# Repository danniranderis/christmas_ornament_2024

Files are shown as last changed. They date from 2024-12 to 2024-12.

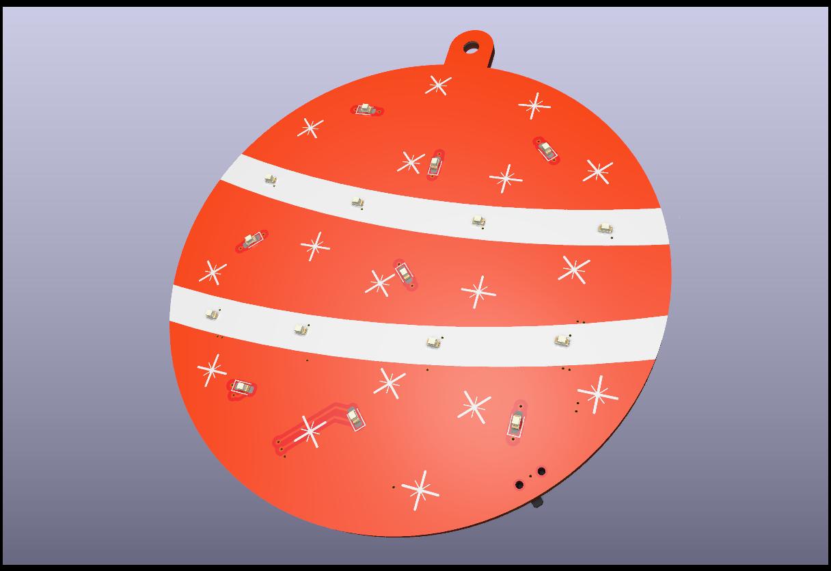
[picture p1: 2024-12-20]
Documentation/christmas_ornament_2024_front_tilt.jpg

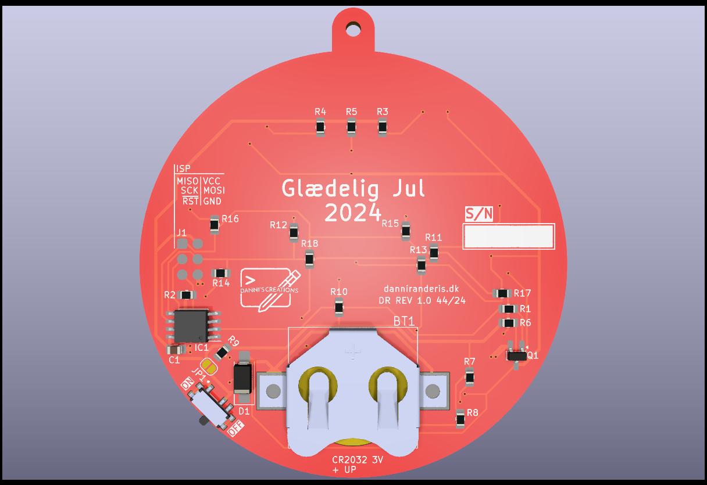
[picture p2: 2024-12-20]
Documentation/christmas_ornament_2024_back.jpg

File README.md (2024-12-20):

# Christmas Ornament 2024
This year marks the second time creating an electronics project for the Christmas holidays.  
The pcb resembles a Christmas ornament-ball in red with silkscreen and LEDs for a twinkling star effect.

## Hardware
The "Hardware" directory within this repository contains PCB design as a KiCAD 8.0 project.

## Firmware
The "Firmware" directory within this repository contains the firmware for the ATtiny13 MCU as an Arduino project.
This utilizes the [Microcore](https://github.com/MCUdude/MicroCore) hardware package.

## Documentation
The "Documentation" directory within this repository contains various documentation-files for the project. Find PDFs, images and alike herewithin.

## Credits
- Danni Randeris <danni@danniranderis.dk>

## License
Copyright 2024 Danni Randeris

This project is licensed under the TAPR Open Hardware License (www.tapr.org/OHL). The "license" folder within this repository contains a copy of this license in plain text format.

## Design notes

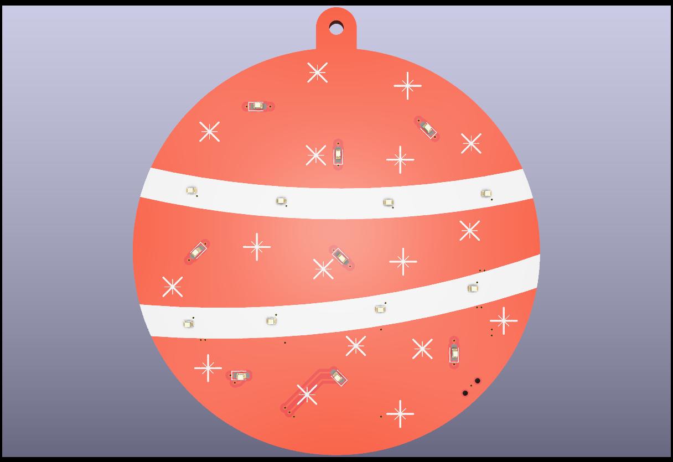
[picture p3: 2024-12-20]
Documentation/christmas_ornament_2024_front.jpg

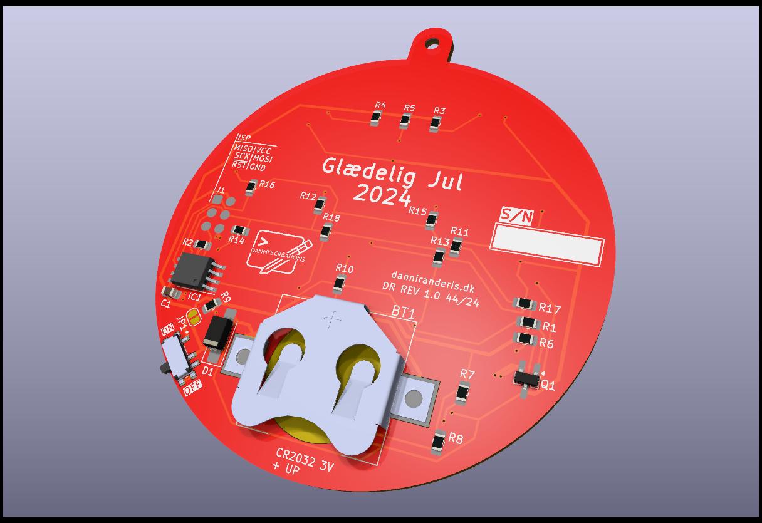
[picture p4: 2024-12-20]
Documentation/christmas_ornament_2024_back_tilt.jpg

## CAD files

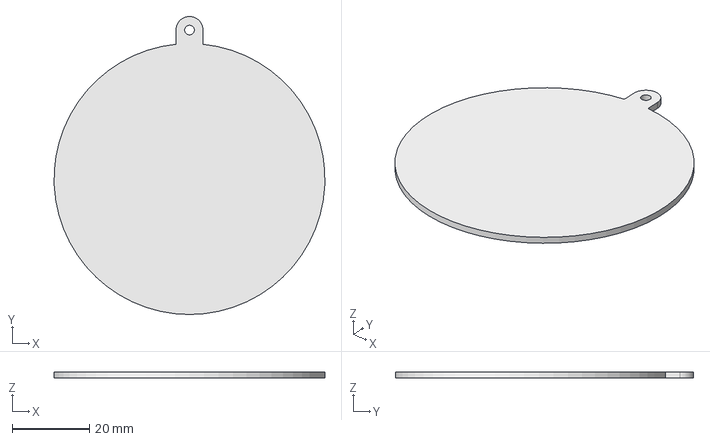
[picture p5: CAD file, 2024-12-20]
Hardware/pcb_edge_cut.FCStd
69.9 x 77.0 x 1.60 mm

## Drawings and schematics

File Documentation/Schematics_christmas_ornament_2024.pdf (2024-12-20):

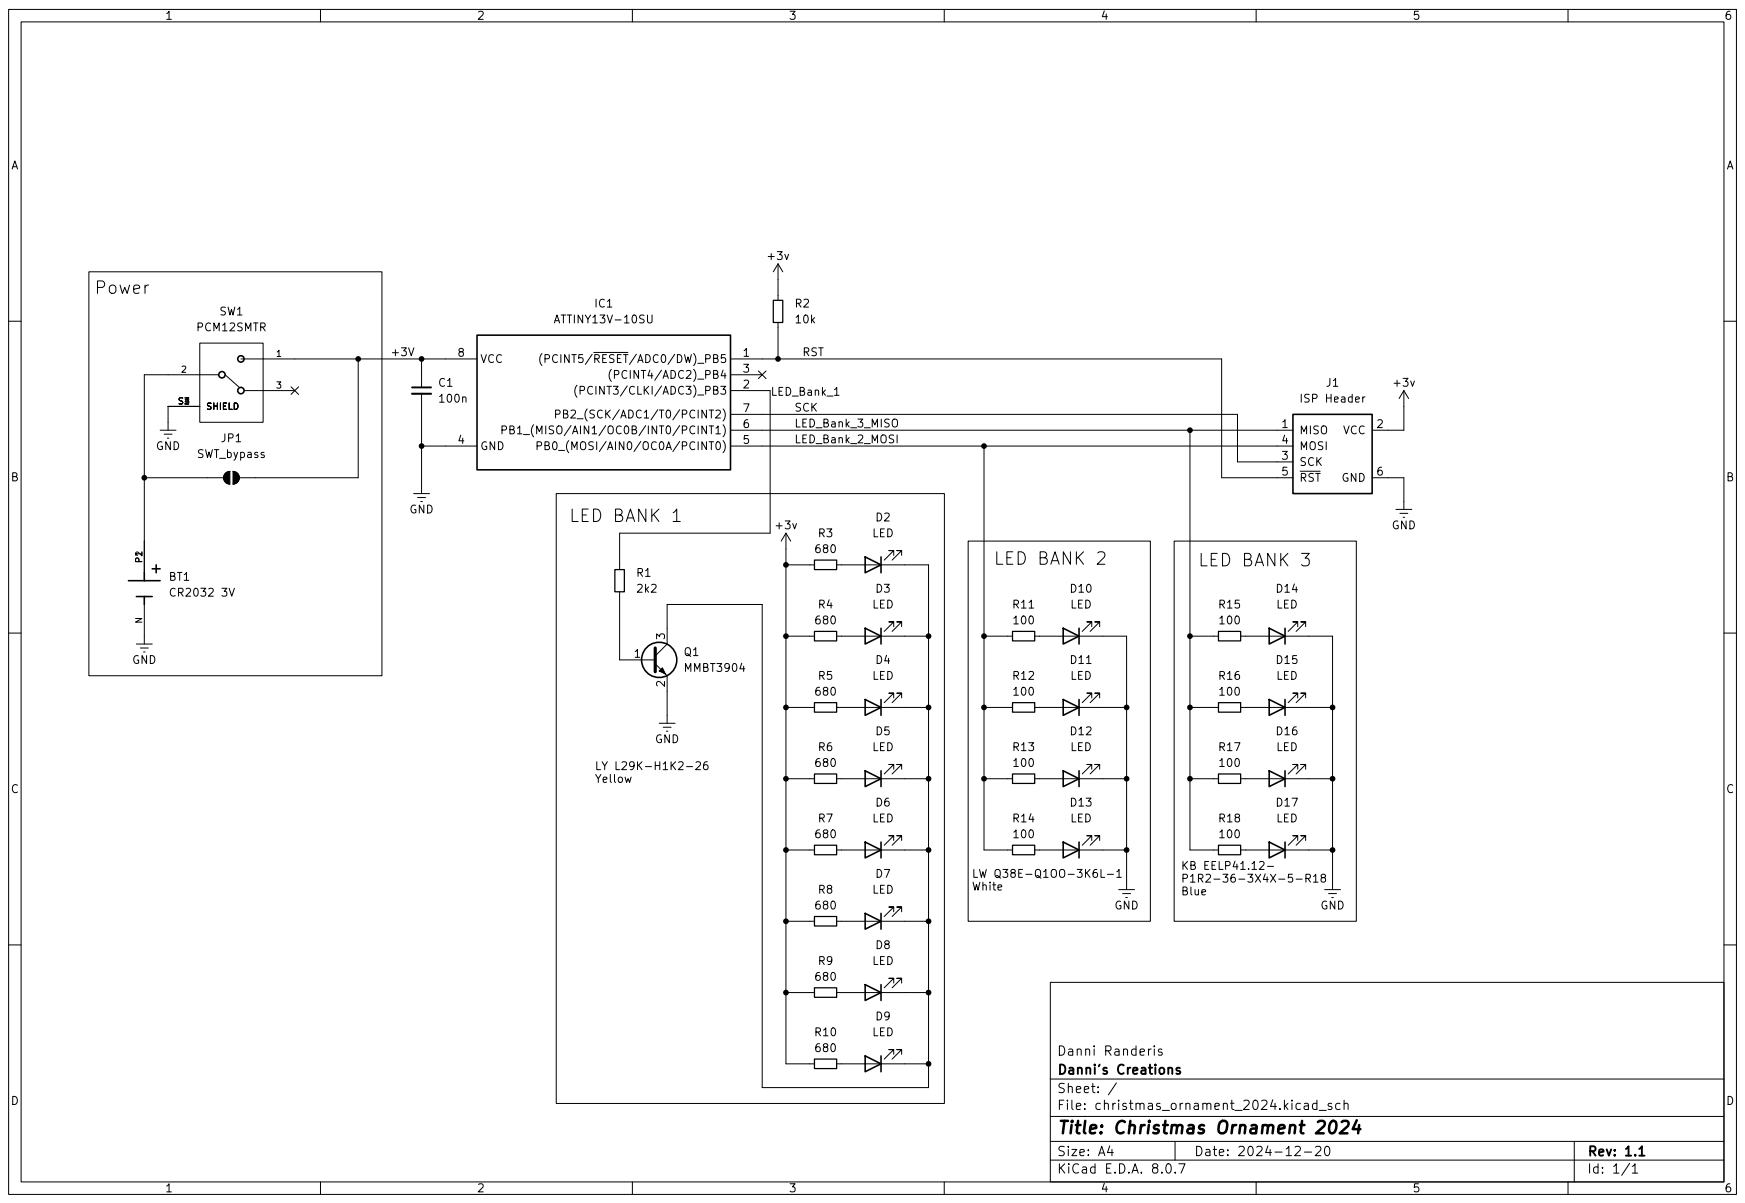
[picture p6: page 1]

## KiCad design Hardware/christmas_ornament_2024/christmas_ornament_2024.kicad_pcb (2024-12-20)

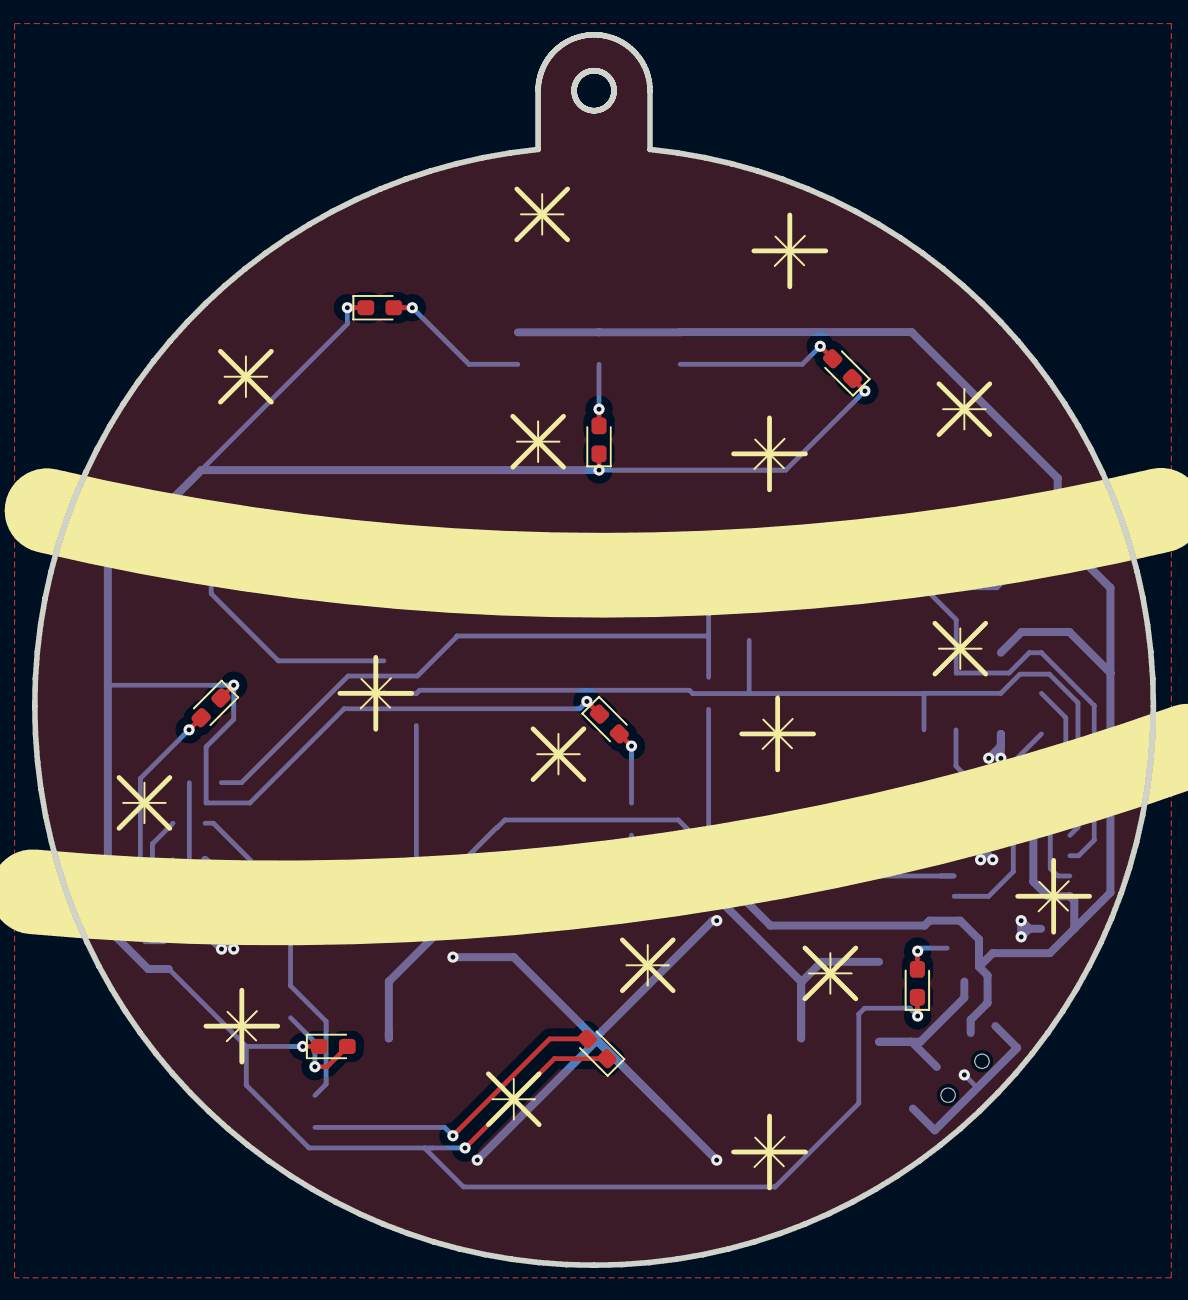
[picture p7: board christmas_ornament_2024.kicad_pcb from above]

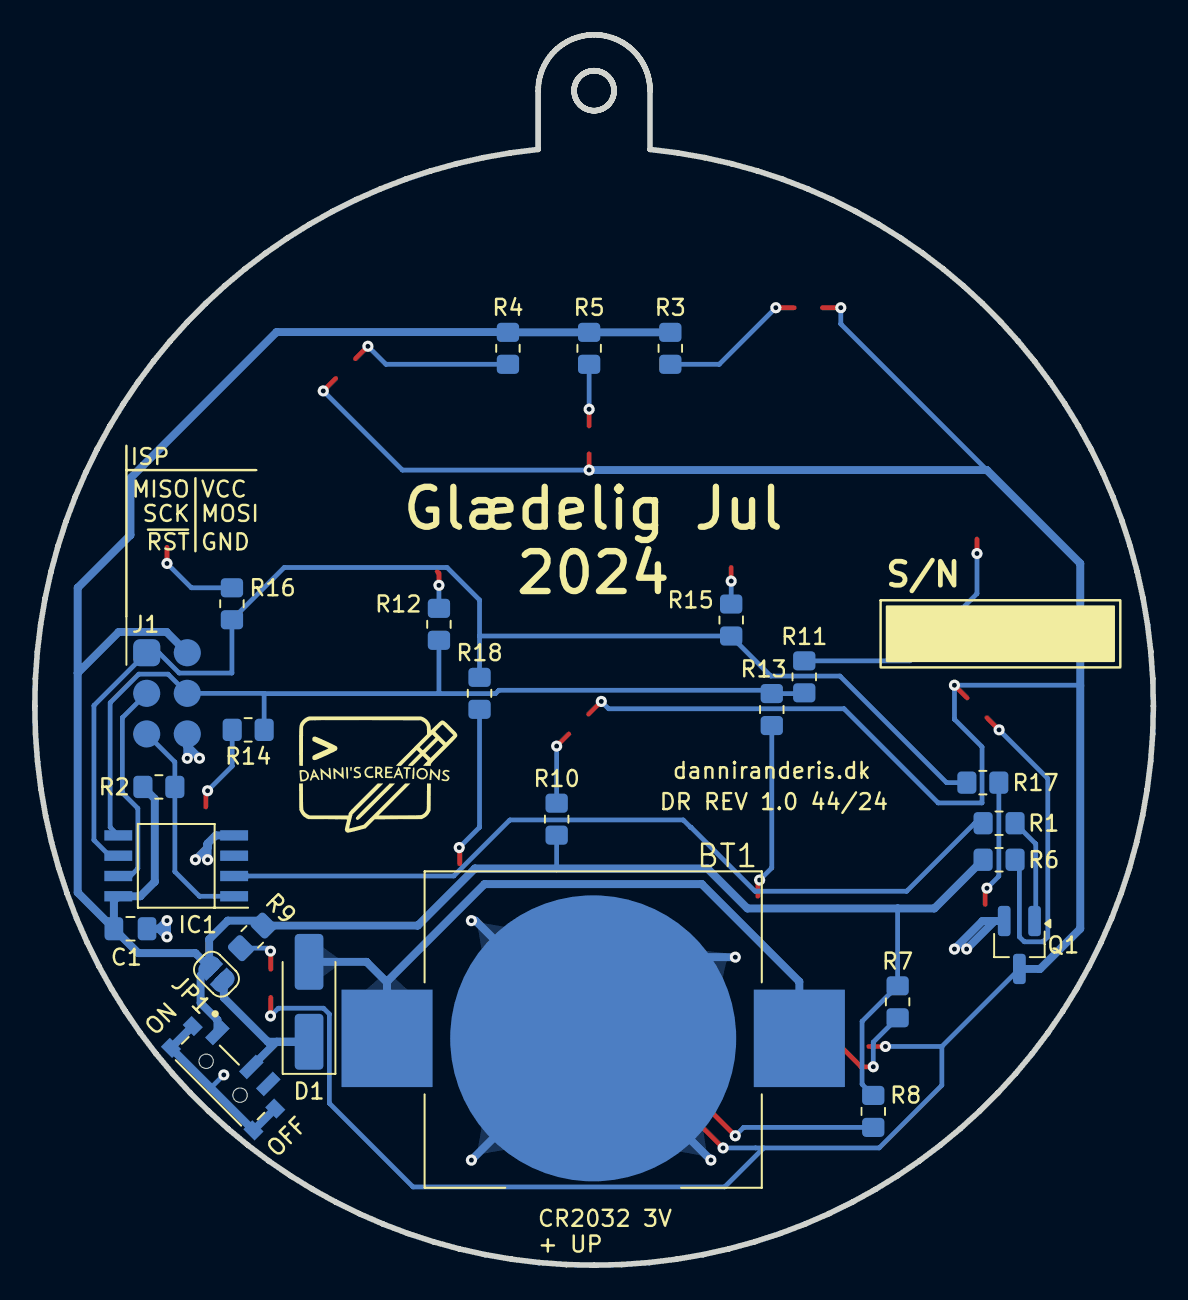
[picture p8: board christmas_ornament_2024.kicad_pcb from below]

Board: 2 copper layers, 70.0 x 77.0 mm, 59 parts (26 on the bottom side), 27 nets.

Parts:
BT1: CR2032 3V; BAT_BAT-HLD-003-SMT
C1: 100n; C_0805_2012Metric_Pad1.18x1.45mm_HandSolder
D1: SS12; D_SMA_Handsoldering
D2, D3, D4, D5, D6, D7, D8, D9, D10, D11, D12, D13, D14, D15, D16, D17: LED; LED_0603_1608Metric_Pad1.05x0.95mm_HandSolder
IC1: ATTINY13V-10SU; SOIC127P798X216-8N
J1: ISP Header; ISP_Pad
JP1: SWT_bypass; SolderJumper-2_P1.3mm_Open_RoundedPad1.0x1.5mm
Q1: MMBT3904; SOT-23_Handsoldering
R1: 2k2; R_0805_2012Metric_Pad1.20x1.40mm_HandSolder
R2: 10k; R_0805_2012Metric_Pad1.20x1.40mm_HandSolder
R3, R4, R5, R6, R7, R8, R9, R10, R11, R12, R13, R14, R15, R16, R17, R18: 470; R_0805_2012Metric_Pad1.20x1.40mm_HandSolder
SW1: PCM12SMTR; SW_PCM12SMTR
U1, U2, U3, U4, U5, U6, U7, U10, U11, U12, U13, U14, U15, U16, U17, U18, U19: star

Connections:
+3V: C1.1, IC1.8 (VCC), J1.2 (VCC), JP1.2 (B), R2.1, R3.1, R4.1, R5.1, R6.1, R7.1, R8.1, R9.1, R10.1, SW1.1
/LED_Bank_1: IC1.2 ((PCINT3/CLKI/ADC3)_PB3), R1.2
/LED_Bank_2_MOSI: IC1.5 (PB0_(MOSI/AIN0/OC0A/PCINT0)), J1.4 (MOSI), R11.1, R12.1, R13.1, R14.1
/LED_Bank_3_MISO: IC1.6 (PB1_(MISO/AIN1/OC0B/INT0/PCINT1)), J1.1 (MISO), R15.1, R16.1, R17.1, R18.1
/RST: IC1.1 ((PCINT5/~RESET/ADC0/DW)_PB5), J1.5 (~RST), R2.2
/SCK: IC1.7 (PB2_(SCK/ADC1/T0/PCINT2)), J1.3 (SCK)
DARAN_GND: BT1.N, C1.2, D10.1 (K), D11.1 (K), D12.1 (K), D13.1 (K), D14.1 (K), D15.1 (K), D16.1 (K), D17.1 (K), IC1.4 (GND), J1.6 (GND), Q1.2 (E), SW1.S1 (SHIELD), SW1.S2 (SHIELD), SW1.S3 (SHIELD), SW1.S4 (SHIELD)
unnamed: BT1.P1, BT1.P2, D1.2 (A)
unnamed: D1.1 (K), JP1.1 (A), SW1.2
unnamed: D2.2 (A), R3.2
unnamed: D2.1 (K), D3.1 (K), D4.1 (K), D5.1 (K), D6.1 (K), D7.1 (K), D8.1 (K), D9.1 (K), Q1.3 (C)
unnamed: D3.2 (A), R4.2
unnamed: D4.2 (A), R5.2
unnamed: D5.2 (A), R6.2
unnamed: D6.2 (A), R7.2
unnamed: D7.2 (A), R8.2
unnamed: D8.2 (A), R9.2
unnamed: D9.2 (A), R10.2
unnamed: D10.2 (A), R11.2
unnamed: D11.2 (A), R12.2
unnamed: D12.2 (A), R13.2
unnamed: D13.2 (A), R14.2
unnamed: D14.2 (A), R15.2
unnamed: D15.2 (A), R16.2
unnamed: D16.2 (A), R17.2
unnamed: D17.2 (A), R18.2
unnamed: Q1.1 (B), R1.1

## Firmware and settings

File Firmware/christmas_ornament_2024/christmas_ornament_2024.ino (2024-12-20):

/**
  Christmas Ornamant 2024 firmware for ATtiny13.

  Three banks of LEDs, Yellow, White, and Blue.
  The Yellow bank is always on, while the white and blue are
  twinkling with seperate randomness.

  Written by Danni Randeris, 2024
 */


/* ----------------- Hardware-specific config ---------------------- */
#define LED_BANK_1 3  // I/O-pin connected to white LED bank
#define LED_BANK_2 0  // I/O-pin connected to purple LED bank
#define LED_BANK_3 1  // I/O-pin connected to yellow LED bank


/* ----------------- Program --------------------------------------- */
void setup() {
  // Set PIN modes
  pinMode(LED_BANK_1, OUTPUT);
  pinMode(LED_BANK_2, OUTPUT);
  pinMode(LED_BANK_3, OUTPUT);
  pinMode(4, INPUT_PULLUP);  // NC, pulled HIGH

  // Power Yellow LED bank on
  digitalWrite(LED_BANK_1, HIGH);
}

void loop() {
  // Use PWM to light the the LED banks with a fenced random
  // intensity and then hold that for a fenced random amount of time.
  analogWrite(LED_BANK_2, random(75, 250));
  analogWrite(LED_BANK_3, random(75, 250));
  delay(random(400));
}
